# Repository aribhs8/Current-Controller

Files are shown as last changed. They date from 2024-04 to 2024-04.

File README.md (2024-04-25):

# Current Controller
An embedded circuit powered by the ATTINY85 MCU. The device uses a series-parallel resistor network with a few transistors to control the flow of current through a specific resistance path, outputting a desired current. The user must specify the correct voltage (1.8V, 3.3V or 5V) to properly determine the correct current.

## 🤔 Motivation
When testing electronics, occasionally the need arises to pass through a specific current to a device. Usually, a tester may want to do this for one of the following reasons:
1. Safety
    - Prevent damage to device under test and testing equipment.
    - Ensure device operates within safe operating limits (avoid overloading and/or overheating)
2. Accuracy
    - Accurately measure device's characteristics (impedance, V-I curves, etc.).
    - Useful for characterizing electronic components.
3. Analysis
    - See how device responds under different operating conditions.
4. Calibration
    - Calibration of testing equipment or device to check measurements.
5. Fault Detection
    - See how current affects operation of device; watch for excessive power consumption, leakage or unexpected voltage drops.

### 🏁 Goal
The goal of this device was to help electronic testers accomplish these different current tests. The device allows the user to output a specific current given information about the desired value and the voltage being passed through.

## ⚙️ Additional Specifications
To control the flow of current, an nxn series-parallel network of resistors was created with a set of MOSFETS to control the flow each resistor by row and column. The ATTINY85 MCU was used to control the entire circuit. The MCU's operations include the following:
- Reading value from 3-way switch about voltage (1.8V, 3.3V, 5V)
- Controlling each MOSFET to direct curret path
- Read input from button indicating desired current
- Control matrix of LEDs to indicate selected current

## 🚀 Quick Start
A PDF file can be found in the Current_Controller directory displaying the overall circuit schematic. The schematic and PCB were created in Altium Designer. The project can be imported into this program to edit the overall schematic or PCB.

## 🚴 Usage
To utilize this circuit, you will need the components found in the BOM file. The PCB must also be fabricated and then the components soldered onto the board. After soldering these components, you can upload the MCU FW onto the device.

Power the device through the PWR header using a voltage of 3.3V. Then place the device between two terminals. Specify the target current and watch as the device produces the desired current for you. You can validate using an ammeter.

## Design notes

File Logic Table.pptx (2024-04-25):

## Logic Table for 3.8V Output

A | B | C | D | E | F | G | H | Result
1 | 0 | 0 | 1 | 0 | 0 | NC | NC | 1 mA
1 | 0 | 0 | 1 | 1 | 0 | NC | NC | 2 mA
1 | 0 | 0 | 1 | 1 | 1 | NC | NC | 5 mA
1 | 1 | 0 | 1 | 0 | 0 | NC | NC | 100 µA
1 | 1 | 0 | 1 | 1 | 0 | NC | NC | 200 µA
1 | 1 | 0 | 1 | 1 | 1 | NC | NC | 500 µA
1 | 1 | 1 | 1 | 0 | 0 | NC | NC | 10 µA
1 | 1 | 1 | 1 | 1 | 0 | NC | NC | 20 µA
1 | 1 | 1 | 1 | 1 | 1 | NC | NC | 500 µA

## Logic Table for 1.8V Output

A | B | C | D | E | F | G | H | A' | B' | C' | D' | E' | F' | G' | H' | Result
1 | 0 | 0 | 1 | 0 | 0 | NC | X | 0 | 0 | 0 | 0 | 0 | 0 | NC | NC | 1 mA
1 | 0 | 0 | 1 | 1 | 0 | NC | X | 0 | 0 | 0 | 0 | 0 | 0 | NC | NC | 2 mA
1 | 0 | 0 | 1 | 1 | 1 | NC | X | 0 | 0 | 0 | 0 | 0 | 0 | NC | NC | 5 mA
1 | 1 | 0 | 1 | 0 | 0 | NC | X | 0 | 0 | 0 | 0 | 0 | 0 | NC | NC | 100 µA
1 | 1 | 0 | 1 | 1 | 0 | NC | X | 0 | 0 | 0 | 0 | 0 | 0 | NC | NC | 200 µA
1 | 1 | 0 | 1 | 1 | 1 | NC | X | 0 | 0 | 0 | 0 | 0 | 0 | NC | NC | 500 µA
1 | 1 | 1 | 1 | 0 | 0 | NC | X | 0 | 0 | 0 | 0 | 0 | 0 | NC | NC | 10 µA
1 | 1 | 1 | 1 | 1 | 0 | NC | X | 0 | 0 | 0 | 0 | 0 | 0 | NC | NC | 20 µA
1 | 1 | 1 | 1 | 1 | 1 | NC | X | 0 | 0 | 0 | 0 | 0 | 0 | NC | NC | 50 µA

## Logic Table for 3.3V Output

A | B | C | D | E | F | G | H | A' | B' | C' | D' | E' | F' | G' | H' | Result
0 | 0 | 0 | 0 | 0 | 0 | NC | X | 1 | 0 | 0 | 1 | 0 | 0 | NC | NC | 1 mA
0 | 0 | 0 | 0 | 0 | 0 | NC | X | 1 | 0 | 0 | 1 | 1 | 0 | NC | NC | 2 mA
0 | 0 | 0 | 0 | 0 | 0 | NC | X | 1 | 0 | 0 | 1 | 1 | 1 | NC | NC | 5 mA
0 | 0 | 0 | 0 | 0 | 0 | NC | X | 1 | 1 | 0 | 1 | 0 | 0 | NC | NC | 100 µA
0 | 0 | 0 | 0 | 0 | 0 | NC | X | 1 | 1 | 0 | 1 | 1 | 0 | NC | NC | 200 µA
0 | 0 | 0 | 0 | 0 | 0 | NC | X | 1 | 1 | 0 | 1 | 1 | 1 | NC | NC | 500 µA
0 | 0 | 0 | 0 | 0 | 0 | NC | X | 1 | 1 | 1 | 1 | 0 | 0 | NC | NC | 10 µA
0 | 0 | 0 | 0 | 0 | 0 | NC | X | 1 | 1 | 1 | 1 | 1 | 0 | NC | NC | 20 µA
0 | 0 | 0 | 0 | 0 | 0 | NC | X | 1 | 1 | 1 | 1 | 1 | 1 | NC | NC | 50 µA

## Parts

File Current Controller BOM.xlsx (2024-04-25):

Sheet: Multi-Level BOM - without subs
Micro Current Board Bill of Materials
PRODUCT NAME | Micro Current Board
APPROVED BY
APPROVAL DATE
PART COUNT | 31
TOTAL COST | $19.29
ITEM NUMBER | ITEM NAME | DESCRIPTION | QUANTITY | ALTERNATIVES | STATUS | SOURCE / SUPPLIER | LINK TO SUPPORTING DOC | COMMENTS | UNIT COST | TOTAL PART COST | STATUS KEY
#1 | N-Channel MOSFET | MOSFET Array 2N-CH (Dual) | 9 | DMN2050LFDB-13 | IN STOCK | Digikey (https://www.digikey.ca/en/products/detail/diodes-incorporated/DMN2050LFDB-13/4570606) | Datasheet (https://www.diodes.com/assets/Datasheets/DMN2050LFDB.pdf) | R_DS = 55mΩ @ V_GS = 2.5V | $0.63 | $5.67 | NOT IN STOCK
 |  |  |  | SQ1912EH-T1_GE3 | IN STOCK | Digikey (https://www.digikey.ca/en/products/detail/vishay-siliconix/SQ1912EH-T1-GE3/6708918) | Datasheet (https://www.vishay.com/docs/67394/sq1912eh.pdf) | R_DS = 0.450 @ V_GS = 1.8V |  |  | BACKORDER
#2 | MCU | 8-bit AVR Microcontroller | 1 | Attiny85 | IN STOCK |  |  |  |  | $0.00 | IN STOCK
#3 | Capacitors | 100 uF Capacitor | 1 | GRM21BR60J107ME15L | IN STOCK | Digikey (https://www.digikey.ca/en/products/detail/murata-electronics/GRM21BR60J107ME15L/6155751) | Datasheet (https://search.murata.co.jp/Ceramy/image/img/A01X/G101/ENG/GRM21BR60J107ME15-01.pdf) | Package size = 0805 | $1.72 | $1.72 | ORDERED
 |  | 0.1 uF Capacitor | 1 | C0805C104K9RAC7800 | IN STOCK | Digikey (https://www.digikey.ca/en/products/detail/kemet/C0805C104K9RAC7800/2211746) | Datasheet (https://content.kemet.com/datasheets/KEM_C1002_X7R_SMD.pdf) | Package size = 0805 | $0.29 | $0.29
#4 | Shift Register | 74HC164 Shift Register | 4 | SN74HC164PW | IN STOCK | Digikey (https://www.digikey.ca/en/products/detail/texas-instruments/SN74HC164PW/1570750) | Datasheet (https://www.ti.com/lit/ds/scls115g/scls115g.pdf) | V_Supply = 2 ~ 6 V | $1.70 | $6.80
 |  |  |  | MC74HC164ADR2G | IN STOCK | Digikey (https://www.digikey.ca/en/products/detail/onsemi/MC74HC164ADR2G/919195) | Datasheet (https://www.onsemi.com/pdf/datasheet/mc74hc164a-d.pdf) | V_Supply = 2 ~ 6 V
#5 | Headers | 2-pin header for powering MCU | 1 | M20-9990246 | IN STOCK | Digikey (https://www.digikey.ca/en/products/detail/harwin-inc/M20-9990246/3728226) | Datasheet (https://cdn.harwin.com/pdfs/C001XX_M20_Series_Connectors.pdf) | Through Hole | $0.18 | $0.18
 |  | 1-pin header for input and output | 2 | HTSW-101-07-L-S | IN STOCK | Digikey (https://www.digikey.ca/en/products/detail/samtec-inc/HTSW-101-07-L-S/6691570) | Datasheet (http://suddendocs.samtec.com/catalog_english/htsw_th.pdf) | Through Hole | $0.29 | $0.58
#6 | LEDs | Red LED | 3 | 150080RS75000 | IN STOCK | Digikey (https://www.digikey.ca/en/products/detail/w%C3%BCrth-elektronik/150080RS75000/4489918) | Datasheet (https://www.we-online.com/katalog/datasheet/150080RS75000.pdf) | [1,2,5] mA current output | $0.26 | $0.78
 |  | Blue LED | 3 | 150080BS75000 | IN STOCK | Digikey (https://www.digikey.ca/en/products/detail/w%C3%BCrth-elektronik/150080BS75000/4489912) | Datasheet (https://www.we-online.com/katalog/datasheet/150080BS75000.pdf) | [100,200,500] µA current output | $0.26 | $0.78
 |  | Amber LED | 3 | 5988150107F | IN STOCK | Digikey (https://www.digikey.ca/en/products/detail/dialight/5988150107F/1291276) | Datasheet (https://media.digikey.com/pdf/Data%20Sheets/Dialight%20PDFs/598_Series_0805_Pkg.pdf) | [10,20,50] µA current output | $0.45 | $1.35
 |  | Green LED | 1 | 150080VS75000 | IN STOCK | Digikey (https://www.digikey.ca/en/products/detail/w%C3%BCrth-elektronik/150080VS75000/4489924) | Datasheet (https://www.we-online.com/katalog/datasheet/150080VS75000.pdf) | Power indicator | $0.26 | $0.26
#7 | PNP Transistors |  |  |  |  |  |  |  |  | $0.00
#8 | SP3T Switch | Switch for specifying input voltage outputted by regulator | 1 | CSS-1310TB | IN STOCK | Digikey (https://www.digikey.ca/en/products/detail/nidec-copal-electronics/CSS-1310TB/1124215) | Datasheet (https://www.nidec-copal-electronics.com/e/catalog/switch/css.pdf) | On-On-On rated for 12V and 100 mA | $0.88 | $0.88
 |  |  |  | CUS-13TB | IN STOCK | Digikey (https://www.digikey.ca/en/products/detail/nidec-copal-electronics/CUS-13TB/1124223) | Datasheet (https://www.nidec-copal-electronics.com/e/catalog/switch/cus.pdf) | On-On-On rated for 4V and 300 mA
#9 | Pushbutton | Button for adjusting output current | 1 |  |  |  |  |  |  | $0.00
#10 | Resistors |  |  |  |  |  |  |  |  | $0.00
 |  |  |  |  |  |  |  |  |  | $0.00
 |  |  |  |  |  |  |  |  |  | $0.00
 |  |  |  |  |  |  |  |  |  | $0.00
 |  |  | 31 |  |  |  |  |  | TOTAL | $19.29

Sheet: - Disclaimer -
Any articles, templates, or information provided by Smartsheet on the website are for reference only. While we strive to keep the information up to date and correct, we make no representations or warranties of any kind, express or implied, about the completeness, accuracy, reliability, suitability, or availability with respect to the website or the information, articles, templates, or related graphics contained on the website. Any reliance you place on such information is therefore strictly at your own risk.

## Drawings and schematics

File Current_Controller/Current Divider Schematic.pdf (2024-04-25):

# Current Divider

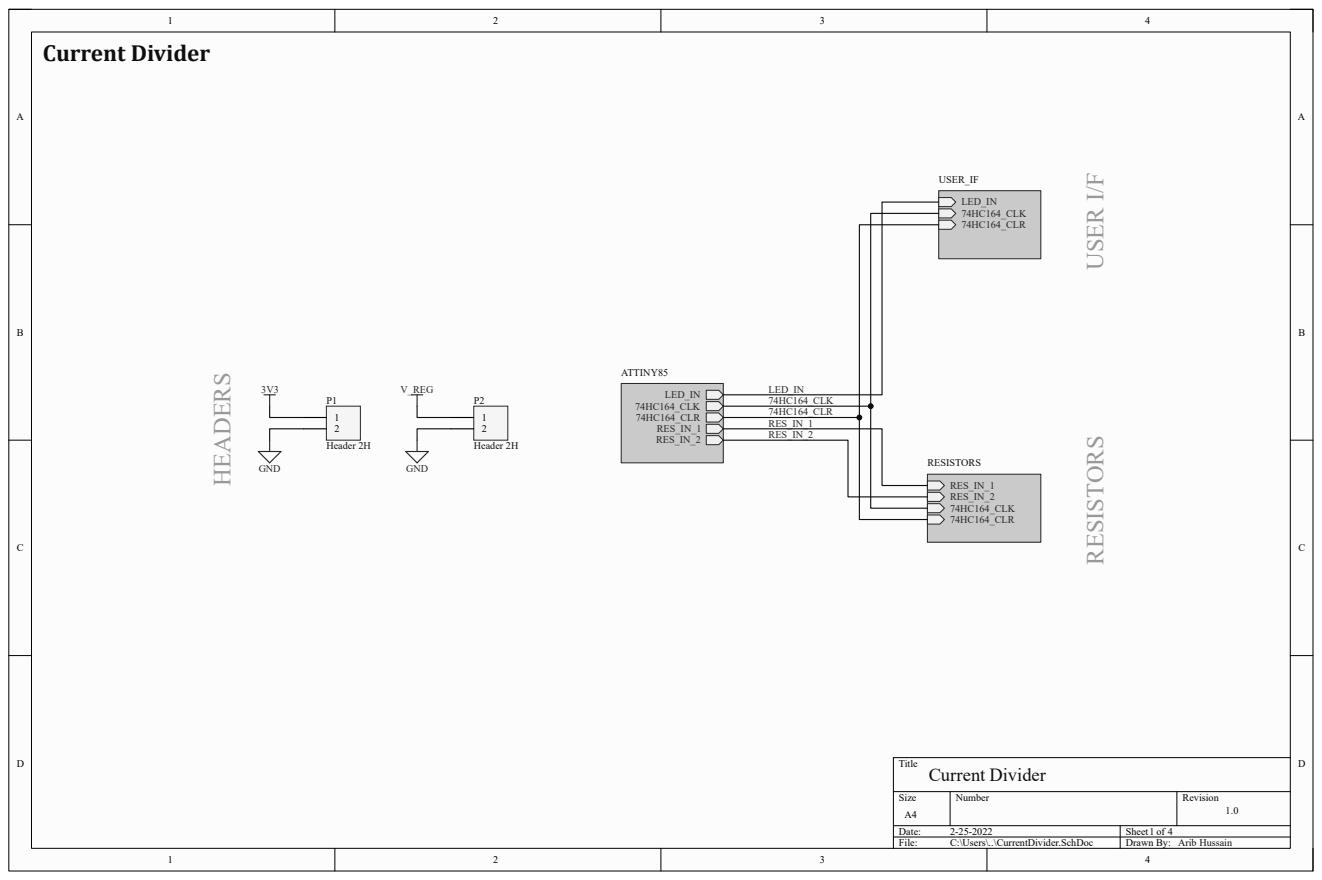
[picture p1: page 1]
Title; Size; Number; Revision; Date:; Sheet of; File:; C:\Users\..\CurrentDivider.SchDoc; Drawn By:; LED_IN 74HC164_CLK 74HC164_CLR; USER_IF; LED_IN 74HC164_CLK 74HC164_CLR RES_IN_1 RES_IN_2; ATTINY85; RES_IN_1; 74HC164_CLK 74HC164_CLR; RES_IN_2; RESISTORS; USER I/F RESISTORS; Current Divider; Arib Hussain; Header 2H; GND; V_REG; GND HEADERS

# USER INTERFACE

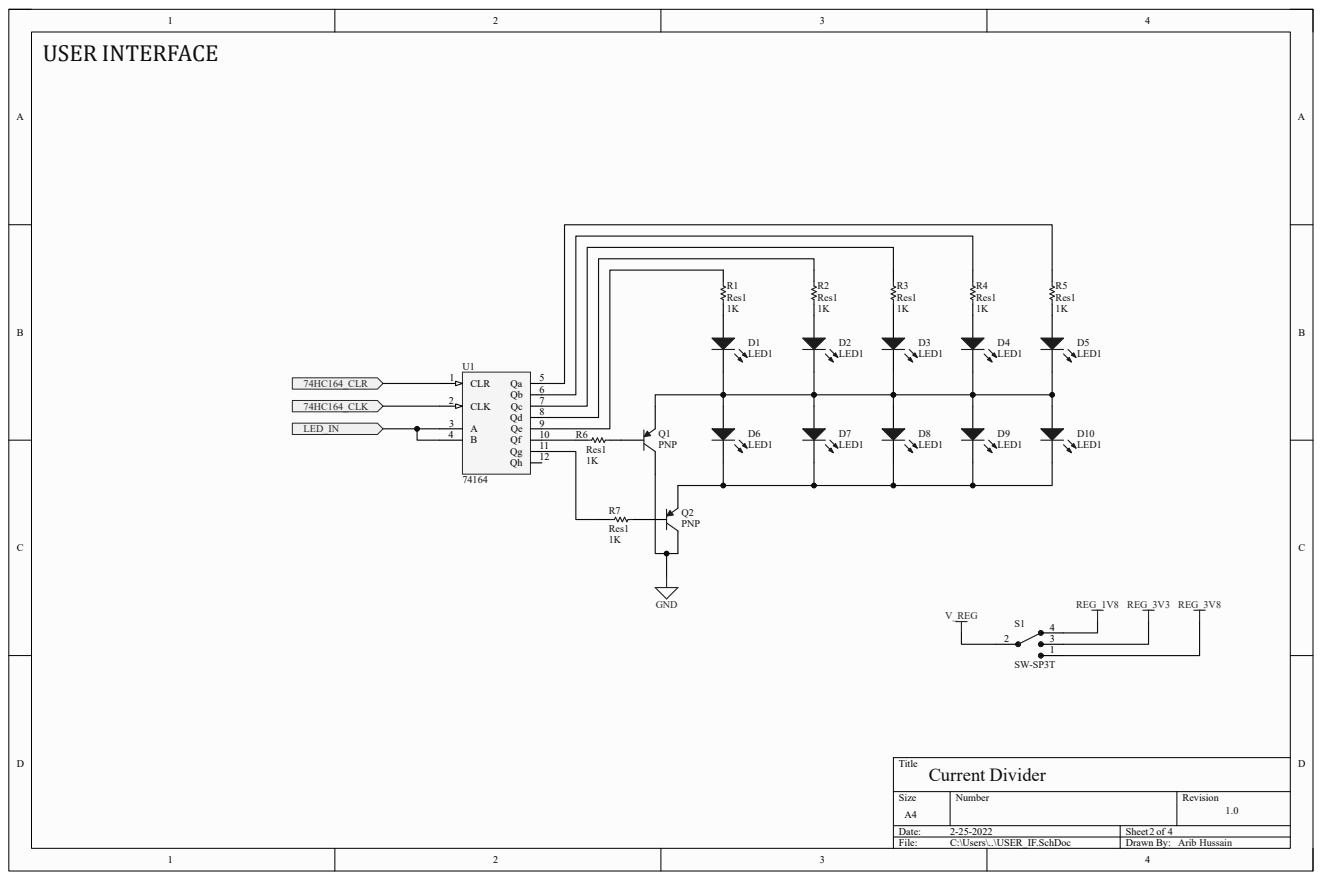
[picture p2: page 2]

# ATTINY85

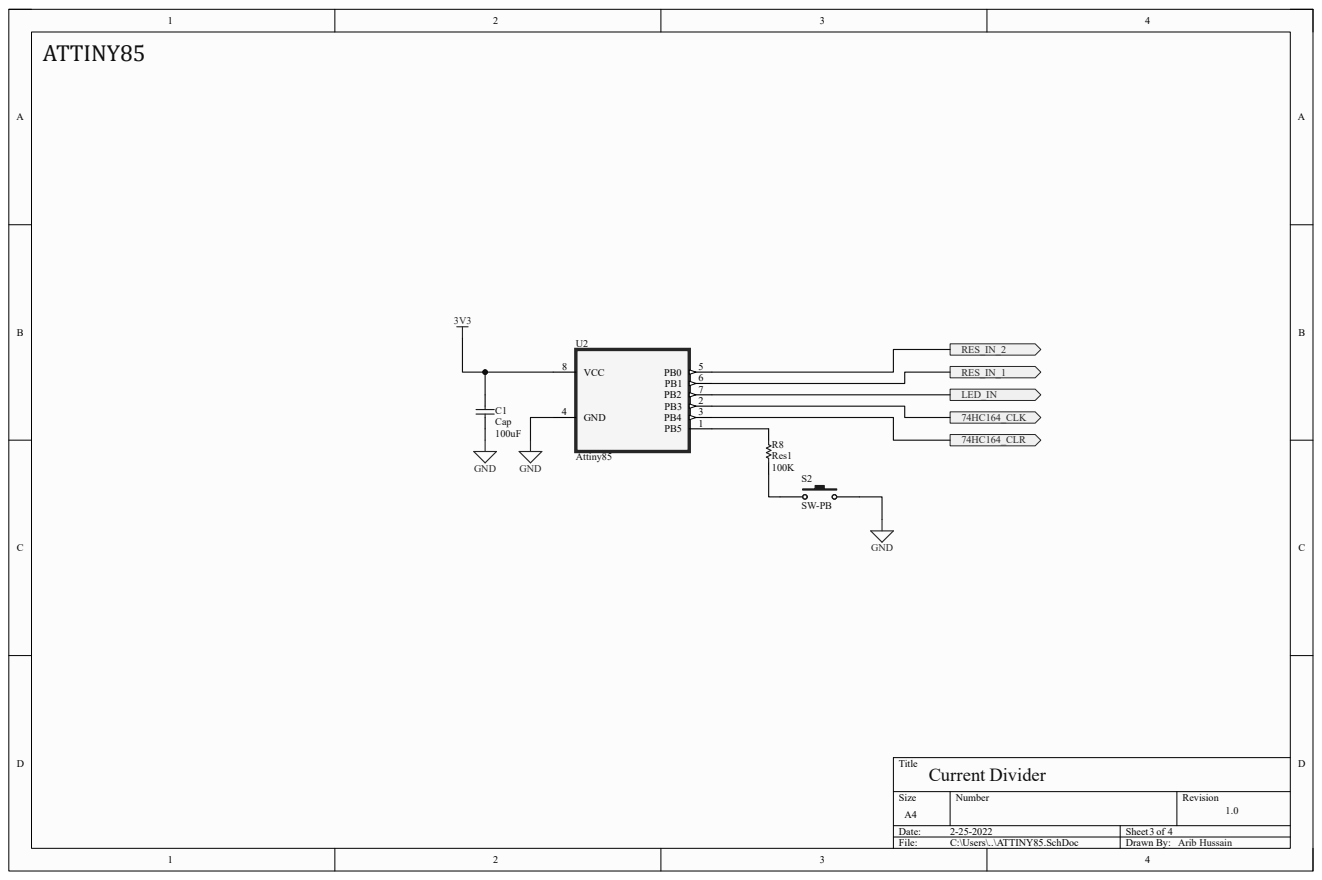
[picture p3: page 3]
Title; Size; Number; Revision; File:; C:\Users\..\ATTINY85.SchDoc; Drawn By:; VCC 8; GND 4; Attiny85; GND; C1 Cap; LED_IN; 74HC164_CLK; 74HC164_CLR; R8 Res1; RES_IN_1; RES_IN_2; Current Divider

RESISTOR NETWORKS RES_IN_1 | 74HC¹⁶⁴_CLK | 74HC¹⁶⁴_CLR

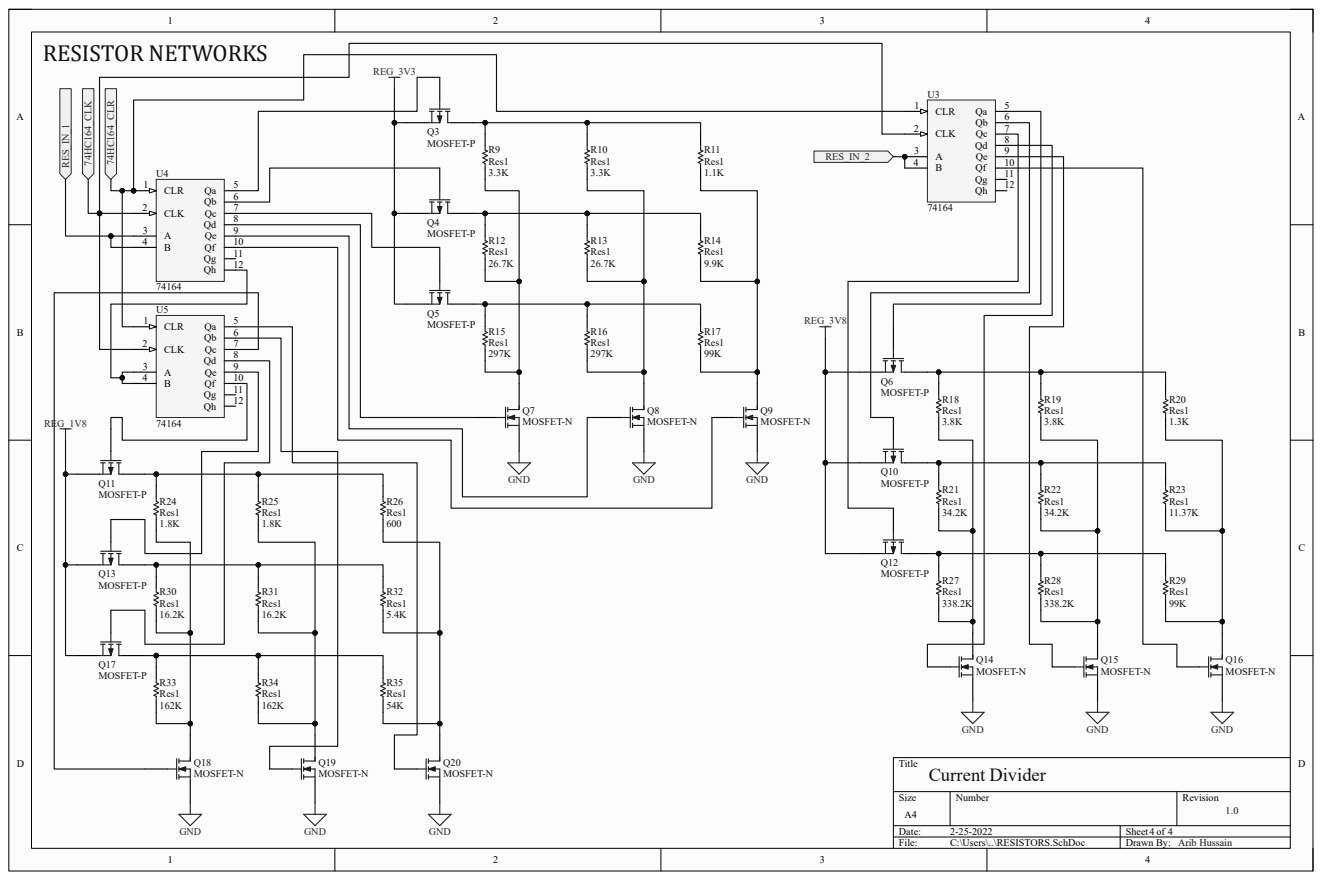
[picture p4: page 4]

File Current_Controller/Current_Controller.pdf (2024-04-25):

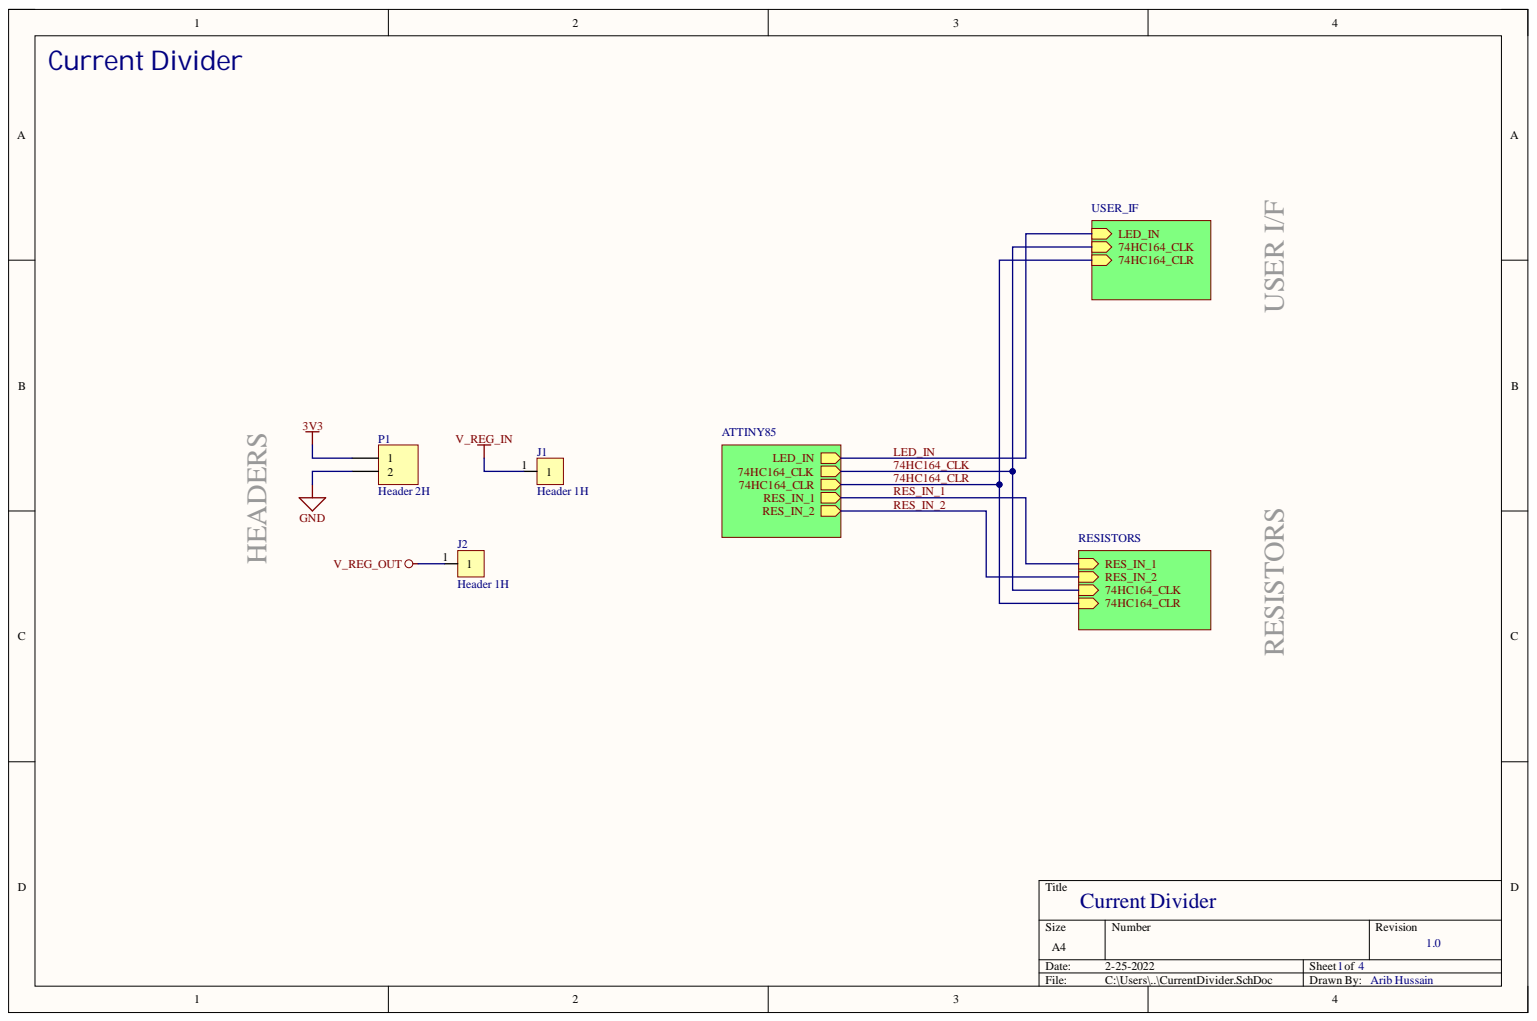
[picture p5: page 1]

7 4 HC1 6 4 _ C LR
RES_IN _ 1
RES_IN _ 2

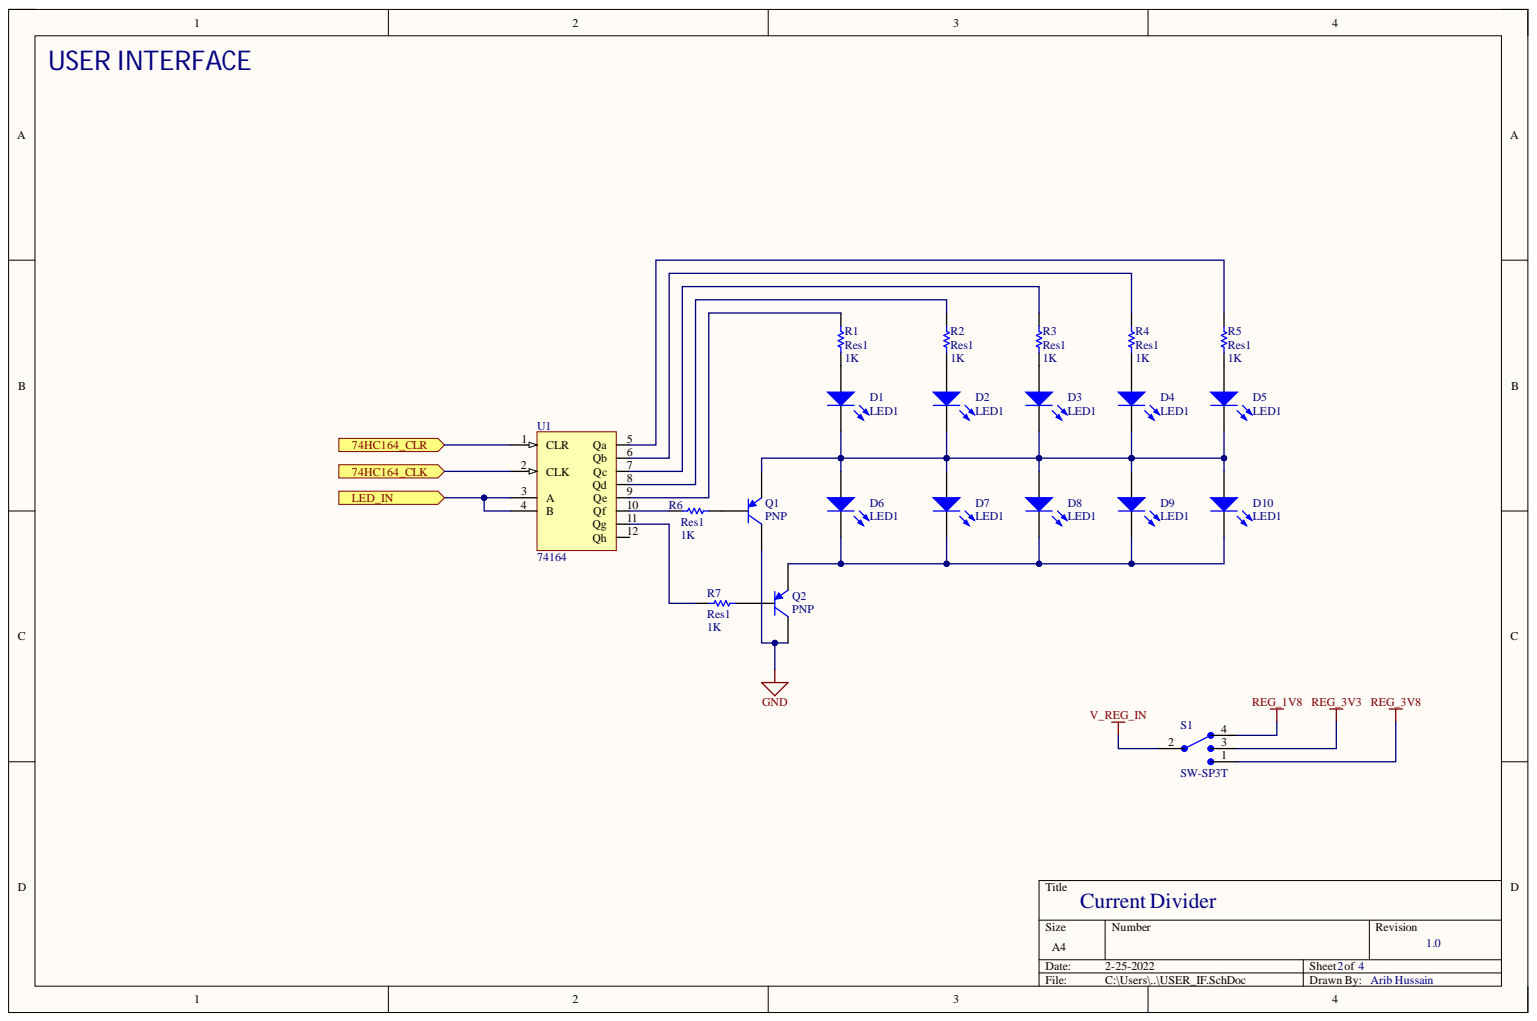
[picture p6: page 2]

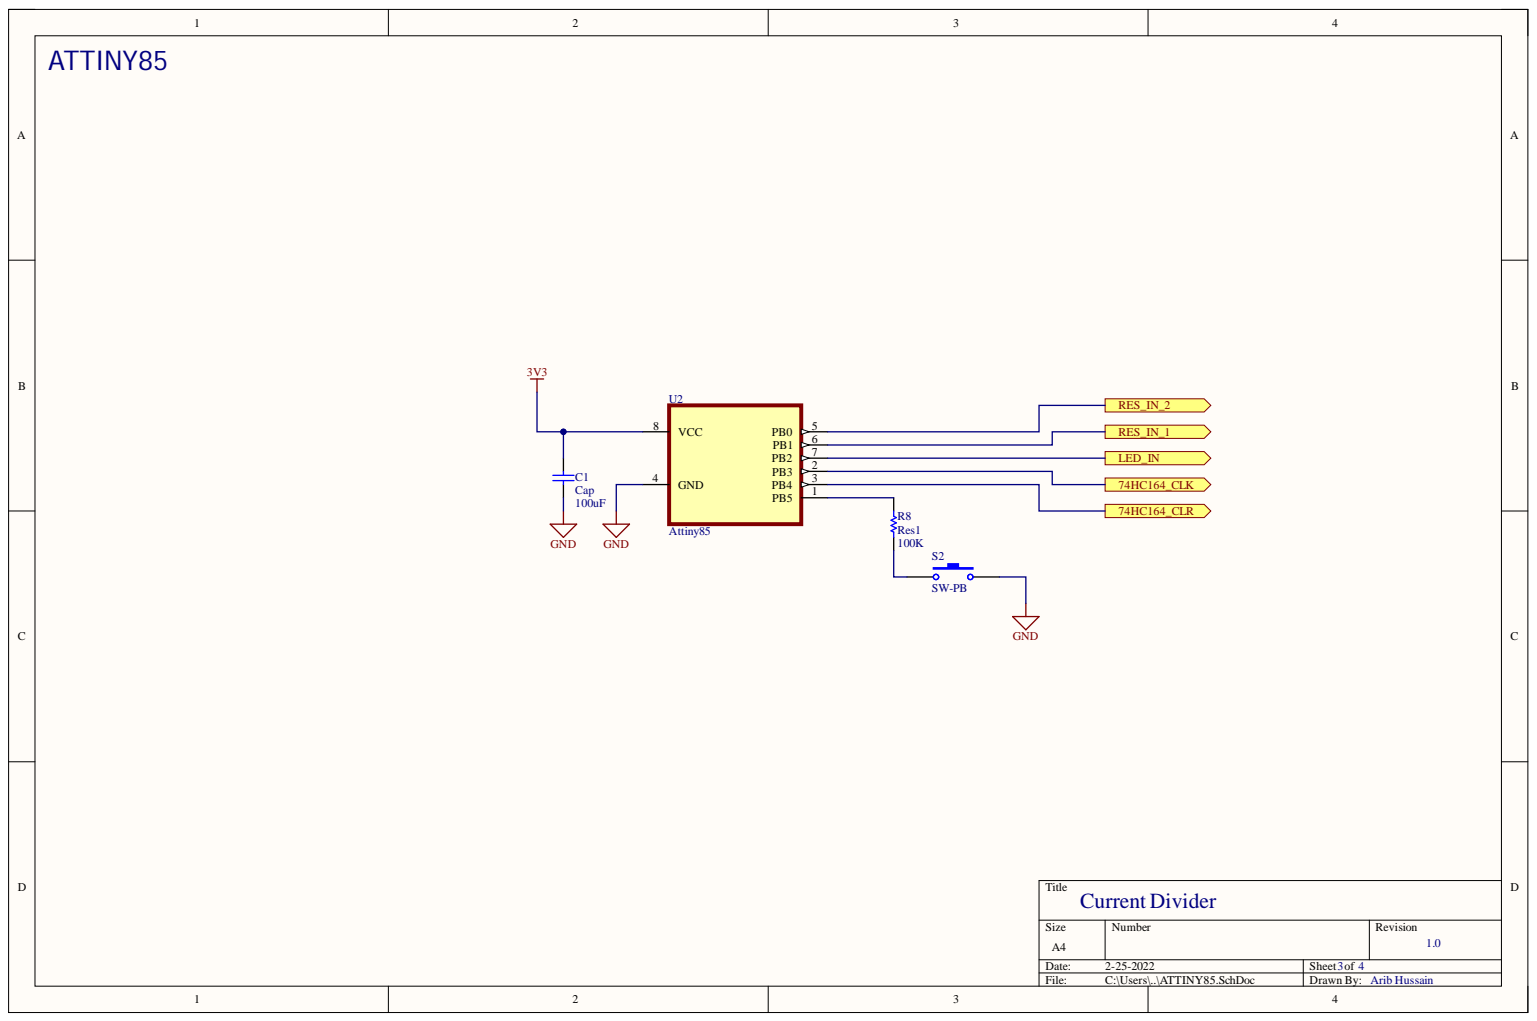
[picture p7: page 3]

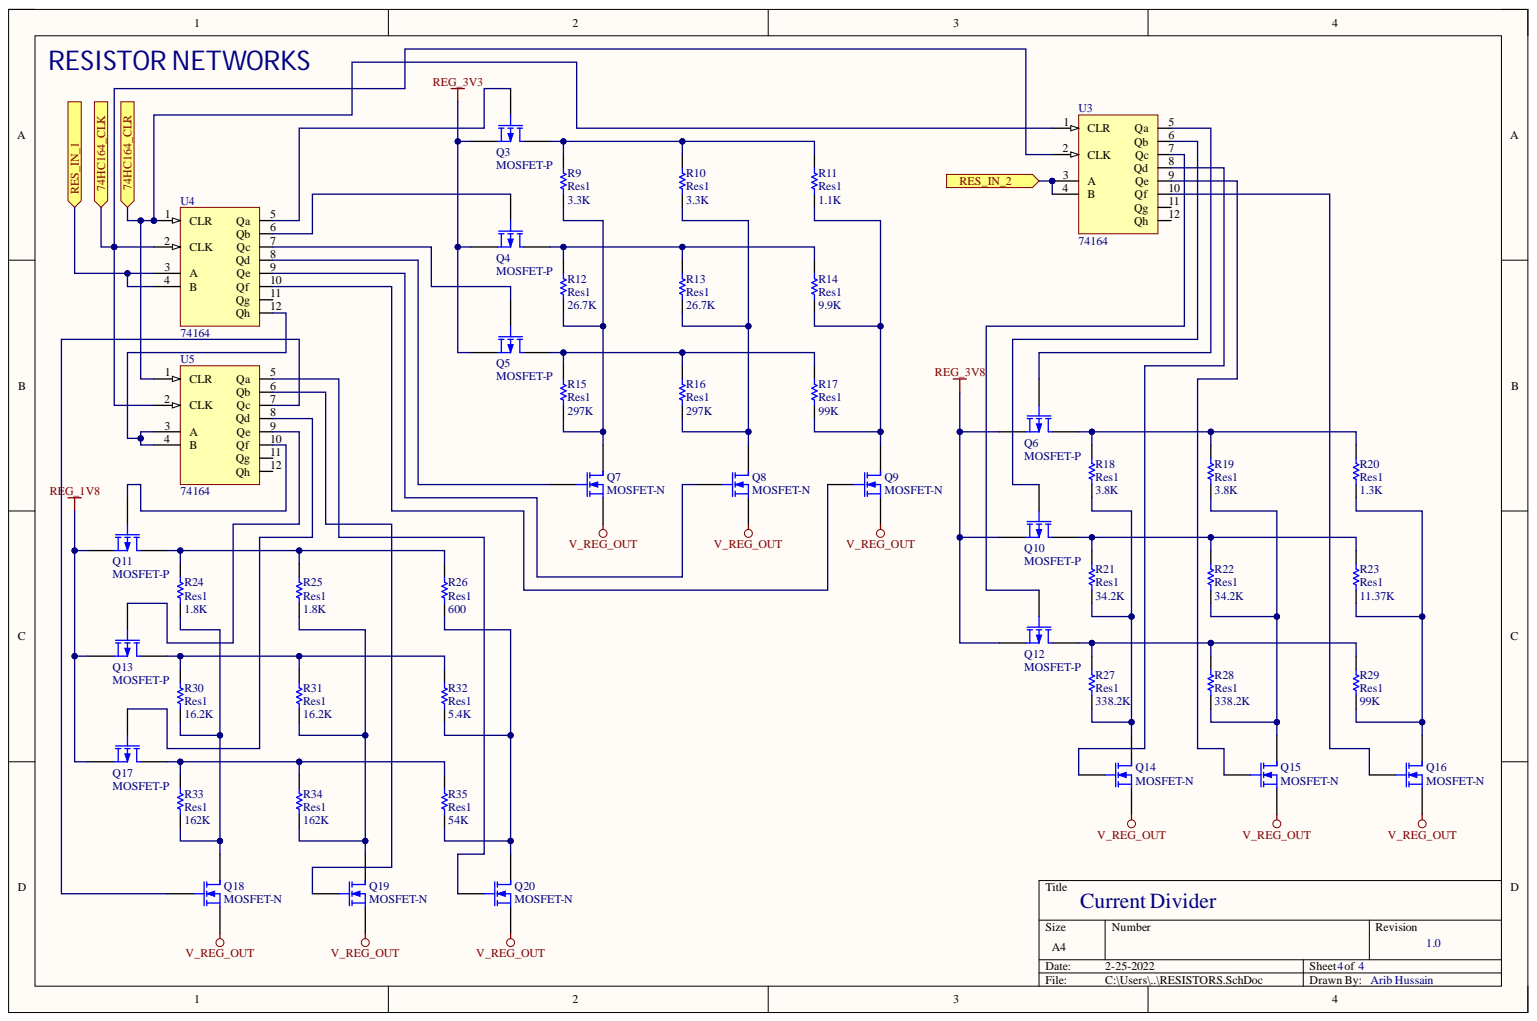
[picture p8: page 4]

9 | | MOSFE | T -P | | R1 2 Res 1 | | R1 3 Res 1 2 6 . 7 K

1 1
1 2

R3 3 Res 1 1 6 2 K | R3 4 Res 1 1 6 2 K

R3 5 Res 1 5 4 K
